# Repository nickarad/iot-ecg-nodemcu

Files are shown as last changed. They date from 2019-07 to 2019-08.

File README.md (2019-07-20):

# Clintelli

<p align="center">
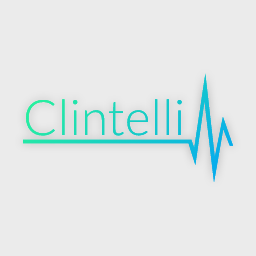
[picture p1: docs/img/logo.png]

</p>

Clintelli stands for Clinical Intelligence and is a platform that leverages Artificial Intelligence and wearable IoT technologies to monitor clinical data and improve patient care.

- [Hackaday 2019 Project](https://hackaday.io/project/165310-clintelli)
- [Documentation](https://nickarad.github.io/clintelli/)

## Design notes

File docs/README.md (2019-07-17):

# Clintelli

Clintelli stands for Clinical Intelligence and is a platform that leverages Artificial Intelligence 
and wearable IoT technologies to monitor clinical data and improve patient care.

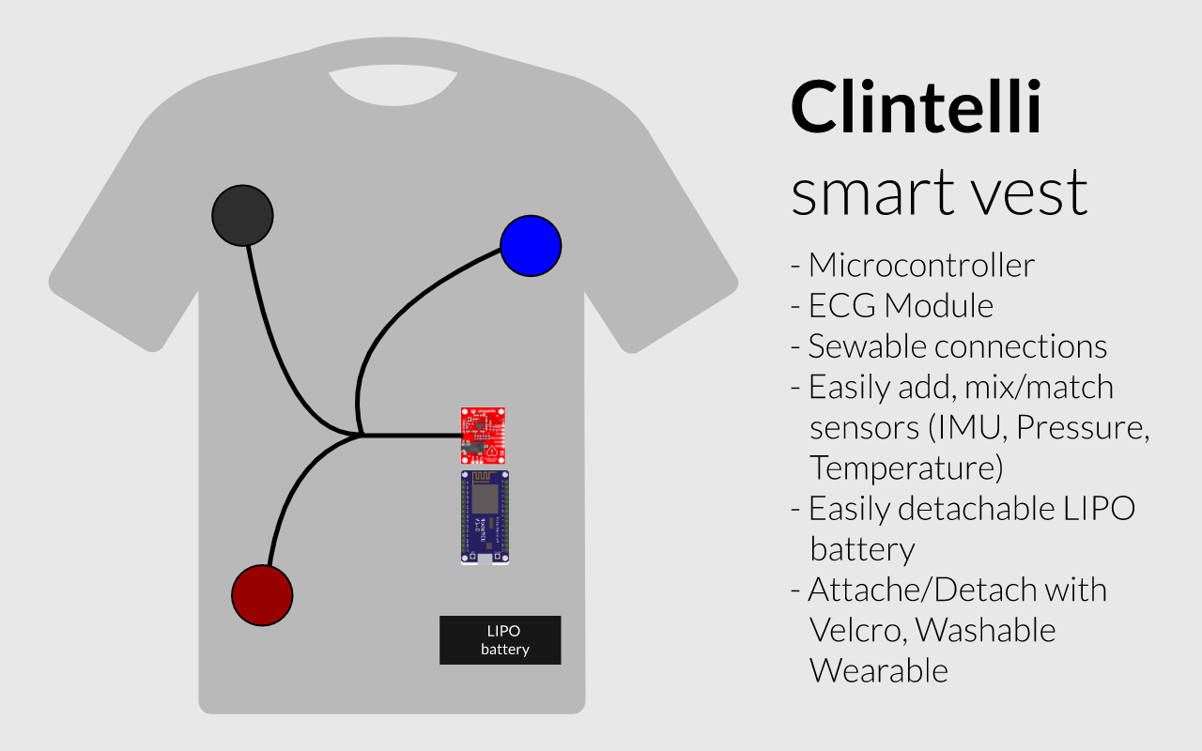
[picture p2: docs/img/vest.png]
clintelli-vest


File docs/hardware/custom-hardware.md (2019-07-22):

# Custom hardware

In order to transform the clintelli IoT wearable prototype into a production ready product, we
decided to design our own customized, open-source, arduino-based microcontroller board, 
the **Clintelli board**.

## Schematics

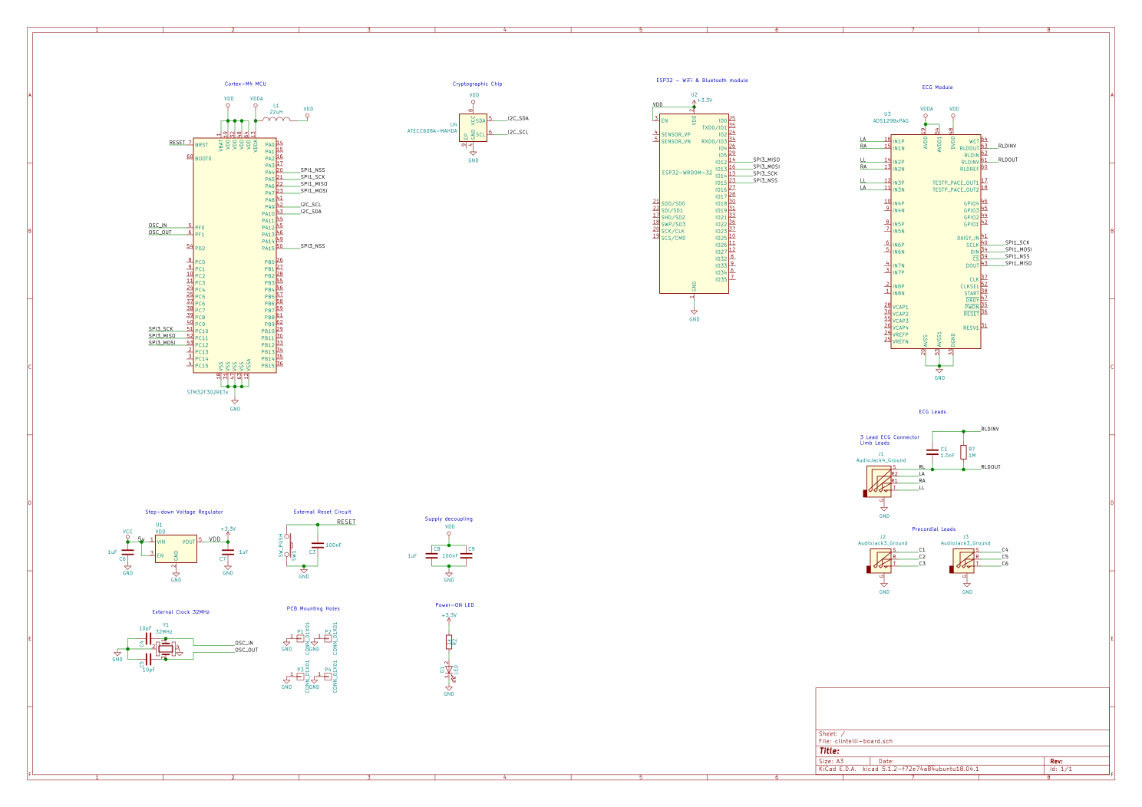
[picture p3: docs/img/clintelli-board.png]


## Components

- Cortex M4 (STM32F302)
- ESP32 (ESP-32-WROOM-32)
- ECG Module (ADS1298)
- Cryptographic chip (ATECC608A)

## ECG Module - MCU SPI

| SPI | ECG GPIO | Cortex M4 Pins | Connection name |
| --- | --- | --- | --- |
| MOSI | 34 | 23 | SPI1_MOSI |
| MISO | 43 | 22 | SPI1_MISO |
| SCK | 40 | 21 | SPI1_SCK |
| SS | 39 | 20 | SPI1_NSS |

## ESP32 Module - MCU SPI

| SPI | ESP32 GPIO | Cortex M4 Pins | Connection name |
| --- | --- | --- | --- |
| MOSI | 13 | 53 | SPI3_MOSI |
| MISO | 12 | 52 | SPI3_MISO |
| SCK | 14 | 51 | SPI3_SCK |
| SS | 15 | 50 | SPI3_NSS |

## PCB Layout

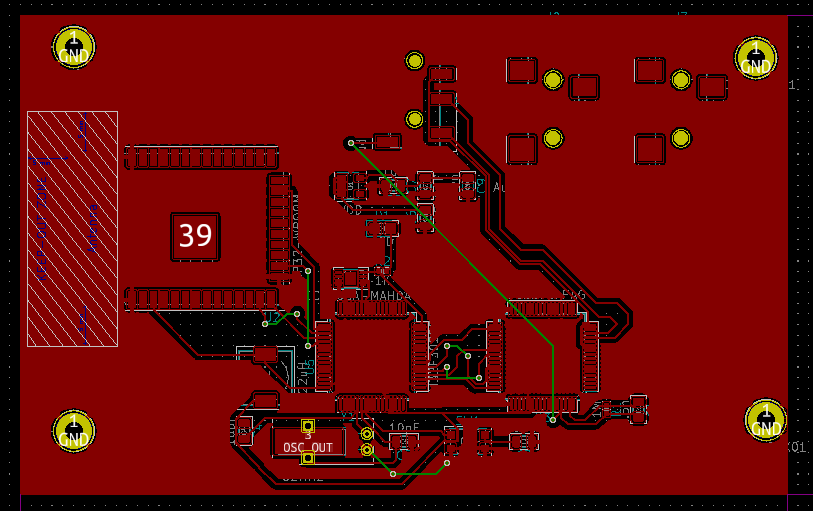
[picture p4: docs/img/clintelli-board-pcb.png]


## PCB Render

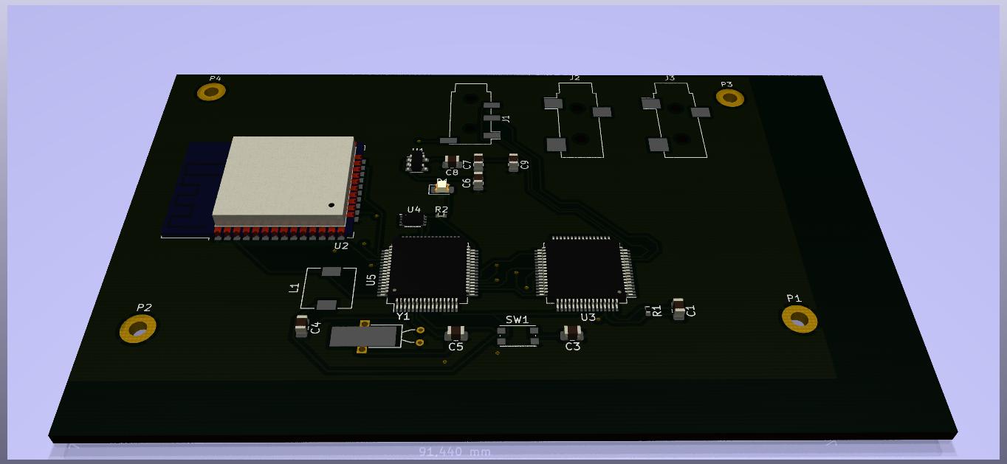
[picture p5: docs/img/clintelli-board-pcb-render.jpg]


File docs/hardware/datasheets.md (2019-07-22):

# Datasheets

- [ARM Cortex-M4 MCU](http://www.st.com/st-web-ui/static/active/en/resource/technical/document/datasheet/DM00133117.pdf)
- [ATECC608A-MAHDA](http://ww1.microchip.com/downloads/en/DeviceDoc/ATECC608A-CryptoAuthentication-Device-Summary-Data-Sheet-DS40001977B.pdf)
- [ESP32-WROOM-32](https://www.espressif.com/sites/default/files/documentation/esp32-wroom-32_datasheet_en.pdf)
- [ADS1298xPAG](http://www.ti.com/lit/ds/symlink/ads1298.pdf)

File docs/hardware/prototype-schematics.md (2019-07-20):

# Schematics

## NodeMCU & ECG module

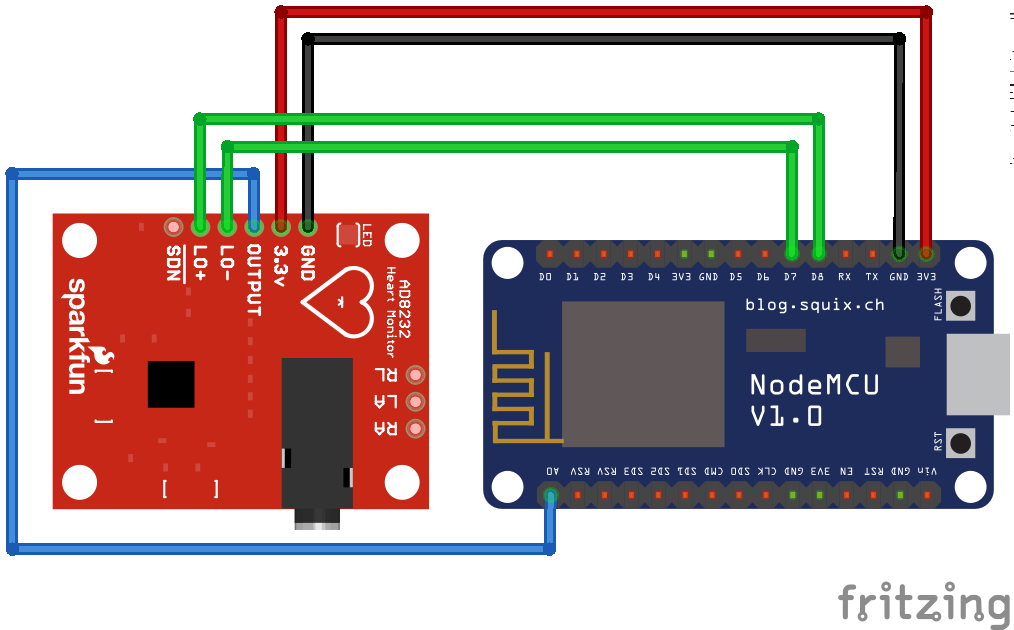
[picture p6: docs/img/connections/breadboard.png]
nodemcu-ecg-breadboard

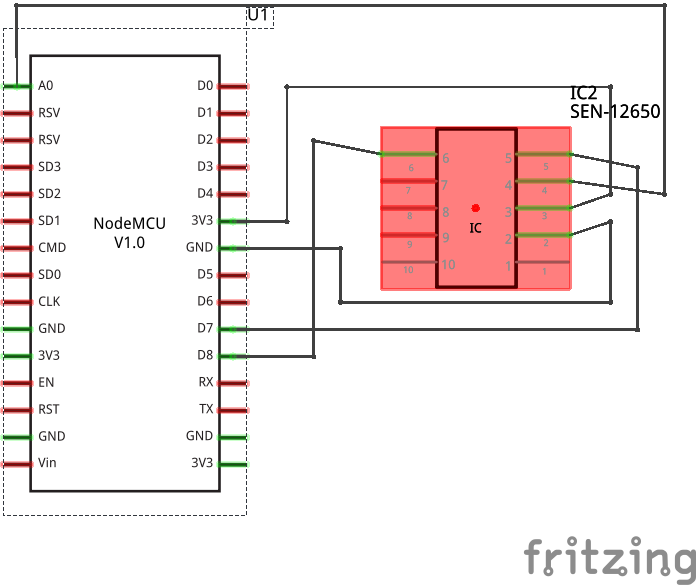
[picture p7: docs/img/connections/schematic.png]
nodemcu-ecg-schematic


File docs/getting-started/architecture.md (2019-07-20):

# Clintelli Platform Architecture

## Platform architecture

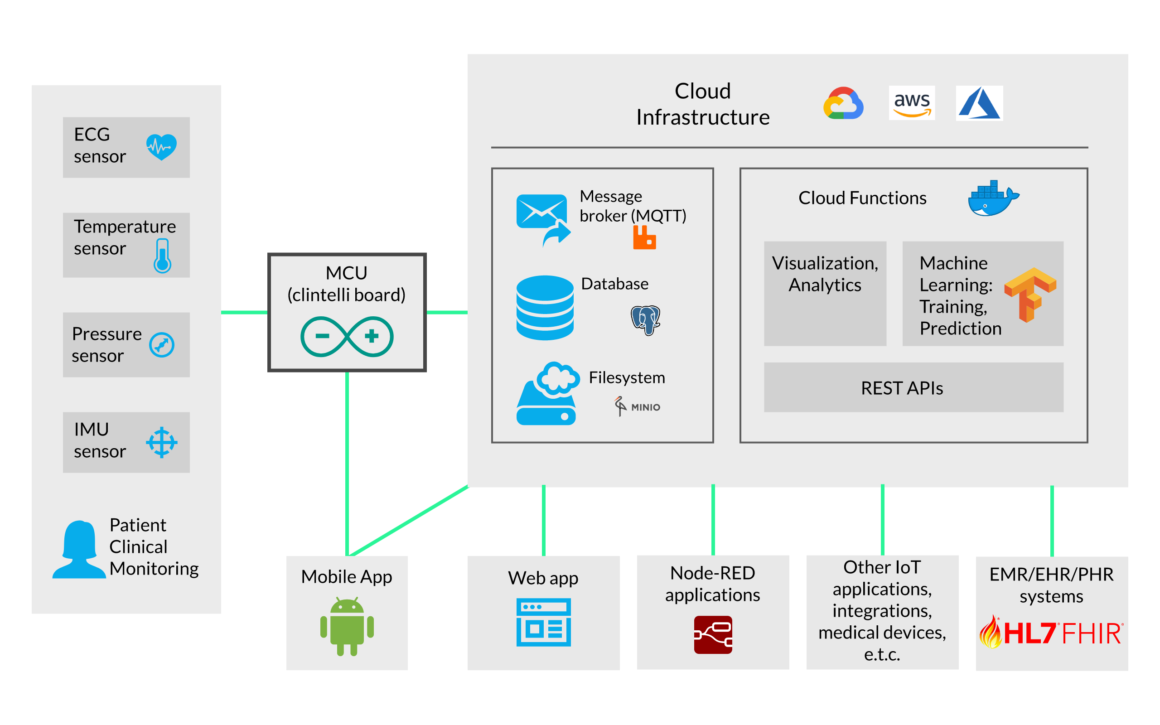
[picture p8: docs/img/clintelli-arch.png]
clintelli-architecture


## Project file structure

- **arduino**: All source code to be compiled and uploaded to an Arduino board
- **cad**: CAD files, Electronics Schematics, PCB layouts, BOMs etc.
- **docker**: Dockerfile and docker-compose configuration file for easily setting up a
    RabbitMQ MQTT server
- **docs**: Clintelli platform documentation
- **sub**: Code for subscribers

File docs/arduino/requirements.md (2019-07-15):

# Requirements

## Hardware

Make sure to prepare the hardware and all the necessary connections as described in
[Schematics](schematics.md)

## Libraries used

- PubSubClient
- ESP8266WiFi

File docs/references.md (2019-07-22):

# References

### ESP8266 based Parts for Fritzing
https://github.com/squix78/esp8266-fritzing-parts.git

### AD8232 Heart Rate Monitor 
https://github.com/sparkfun/AD8232_Heart_Rate_Monitor.git

### RabbitMQ for IoT
https://funprojects.blog/2018/12/07/rabbitmq-for-iot/

### RabbitMQ - MQTT Protocol
https://www.rabbitmq.com/mqtt.html

### MQTT Quality of Service 
https://www.hivemq.com/blog/mqtt-essentials-part-6-mqtt-quality-of-service-levels/

### Arduino CLient for MQTT
https://pubsubclient.knolleary.net/index.html

### DIY Arduino
https://github.com/baldengineer/addohms/tree/master/Episode%2023%20Corrected

### Serial Peripheral Interface (SPI)
https://learn.sparkfun.com/tutorials/serial-peripheral-interface-spi/all

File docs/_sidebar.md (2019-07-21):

- [Home](/)
- Getting Started
    - [Architecture](getting-started/architecture.md)
    - [Quickstart](getting-started/quickstart.md)
- Arduino
    - [Requirements](arduino/requirements.md)
    - [Setup](arduino/setup.md)
- Hardware
    - [Prototype Schematics](hardware/prototype-schematics.md)
    - [Custom Hardware](hardware/custom-hardware.md)
    - [Datasheets](hardware/datasheets.md)
- Deployment
    - [RabbitMQ](deployment/rabbitmq.md)
    - [Google Cloud IoT - Deprecated](deployment/google-iot.md)
- [References](references.md)

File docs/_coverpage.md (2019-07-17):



# Clintelli <small>0.1</small>

> Clinical Intelligence: modular IoT wearable and AI for clinical data monitoring

[GitHub](https://github.com/nickarad/clintelli)
[Get Started](#clintelli)

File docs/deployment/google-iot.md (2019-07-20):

# Google Cloud IoT setup [DEPRECATED]

## Requirements

- An active Google Cloud account
- Google cloud cli

## Instructions

Create topic
```
gcloud pubsub topics create clintelli-test-topic1 --project=PROJECT_ID
```

Create a subscription to the topic above
```
gcloud pubsub subscriptions create clintelli-test-sub1 --topic-project=PROJECT_ID --topic=clintelli-test-topic1 
```

if you want to avoid specifying each time the project with `--project` flag you can run the following
```
gcloud config set project PROJECT_ID
```

Create IoT registry
```
gcloud iot registries create clintelli-test-registry1 --region=europe-west1 --event-notification-config=topic=clintelli-test-topic1
```

Generate certificates
```
openssl req -x509 -newkey rsa:2048 -keyout clintelli-test-rsa_private.pem -nodes -out rsa_cert.pem -subj "/CN=unused"
openssl ecparam -genkey -name prime256v1 -noout -out clintelli-test-ec_private.pem
openssl ec -in clintelli-test-ec_private.pem -pubout -out clintelli-test-ec_public.pem
```

Store above certificates safely and use them to create a device
```
gcloud iot devices create 'clintelli-test' --region=europe-west1 --registry=clintelli-test-registry1 --public-key=path=./clintelli-test-ec_public.pem,type=es256
```

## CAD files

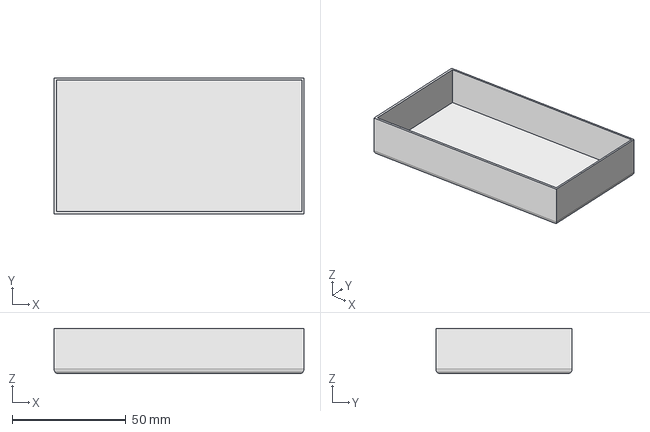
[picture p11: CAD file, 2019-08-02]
cad/board-house/board-house.FCStd
110.0 x 60.0 x 20.0 mm

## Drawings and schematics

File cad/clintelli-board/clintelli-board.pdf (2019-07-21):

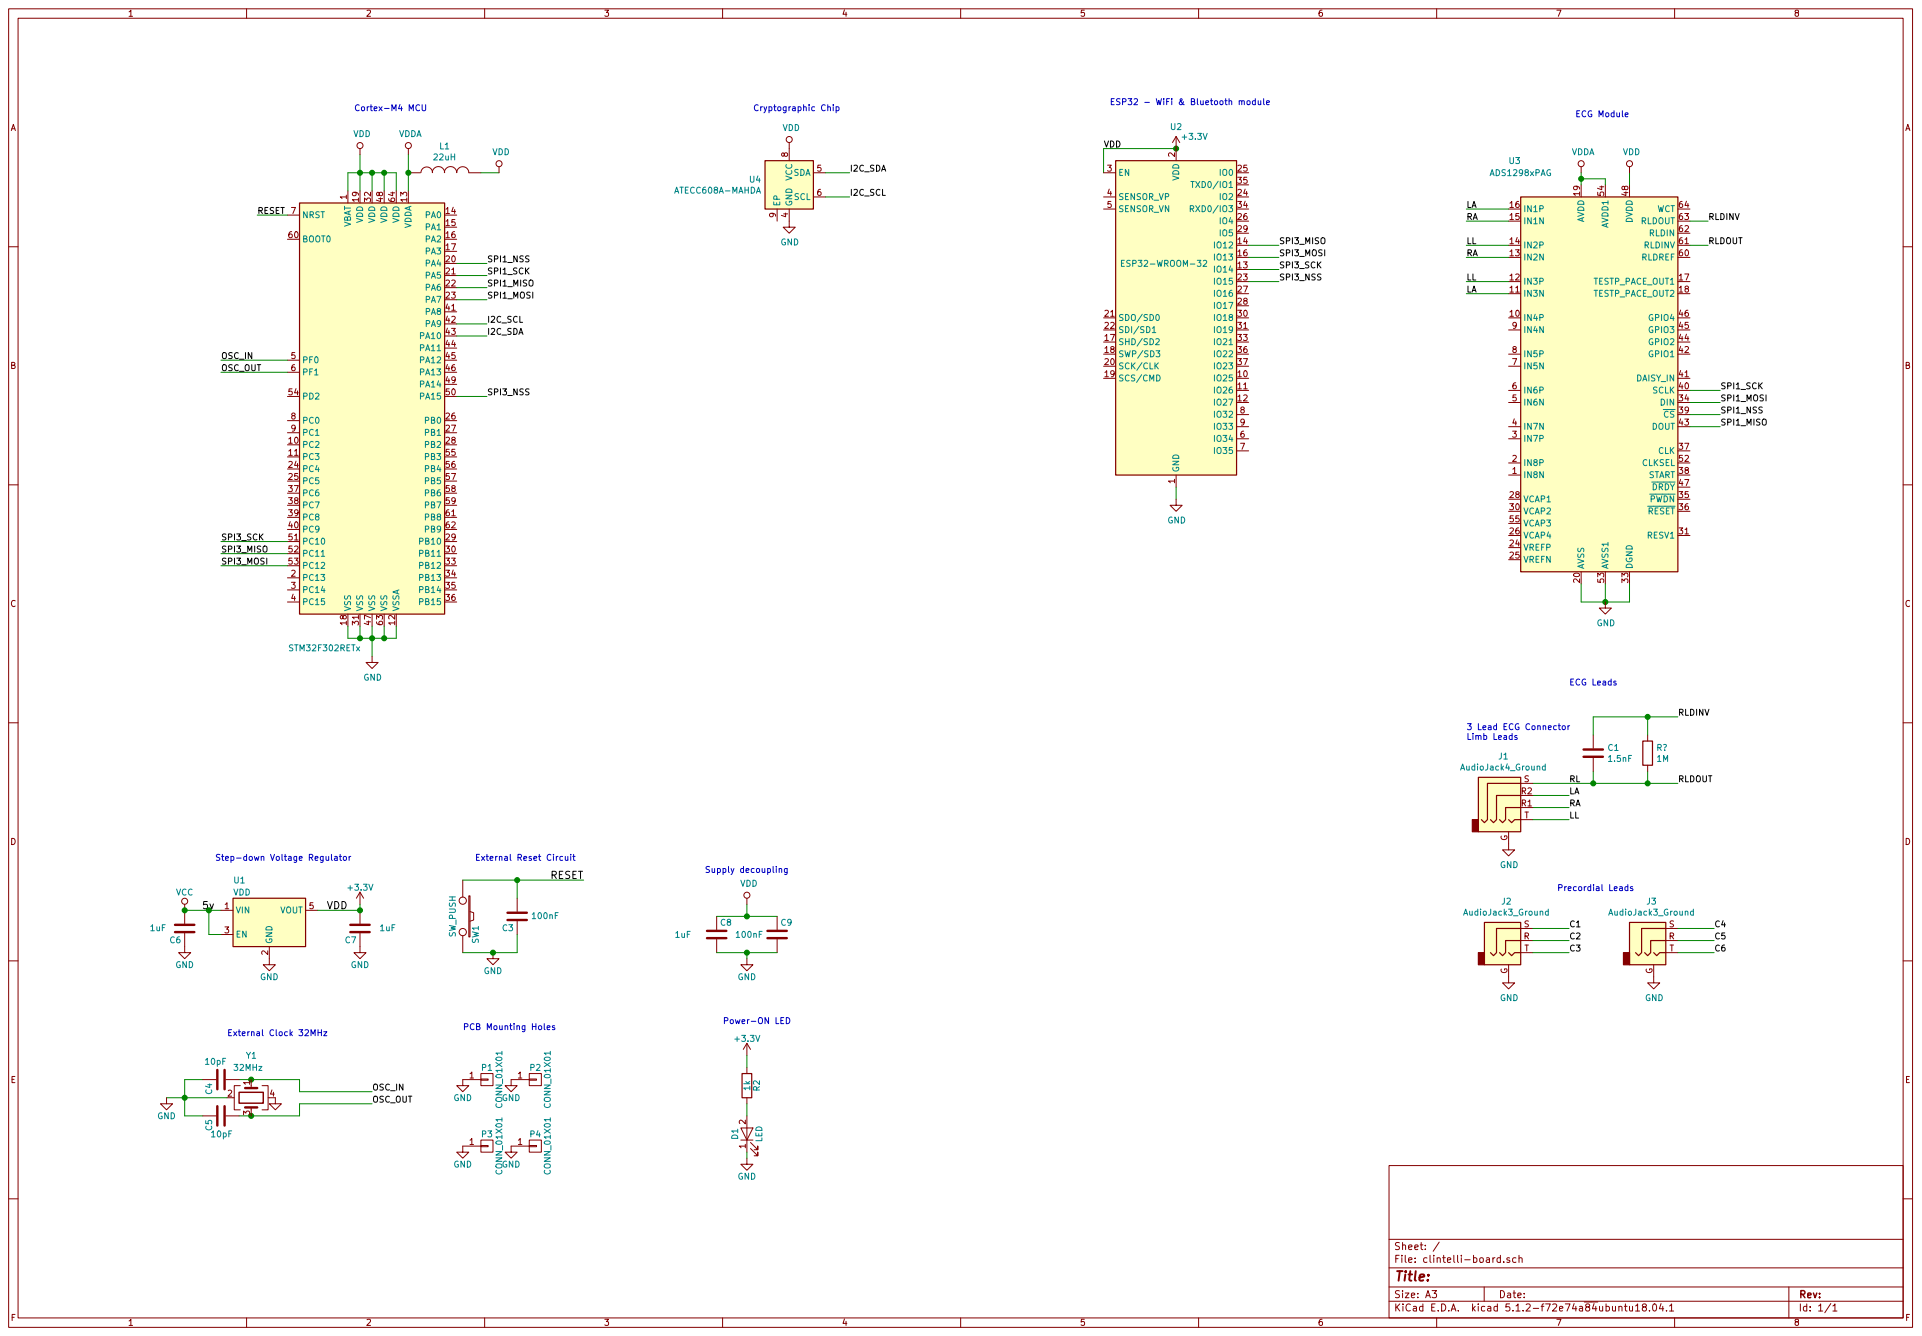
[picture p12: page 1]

VDD
RLDINV RLDOUT RLDINV RLDOUT ECG Leads G

3 Lead ECG Connector Limb Leads

Step-down Voltage Regulator

Id: 1/1 Title: File: clintelli-board.sch Sheet: / GND

PCB Mounting Holes External Clock 32MHz

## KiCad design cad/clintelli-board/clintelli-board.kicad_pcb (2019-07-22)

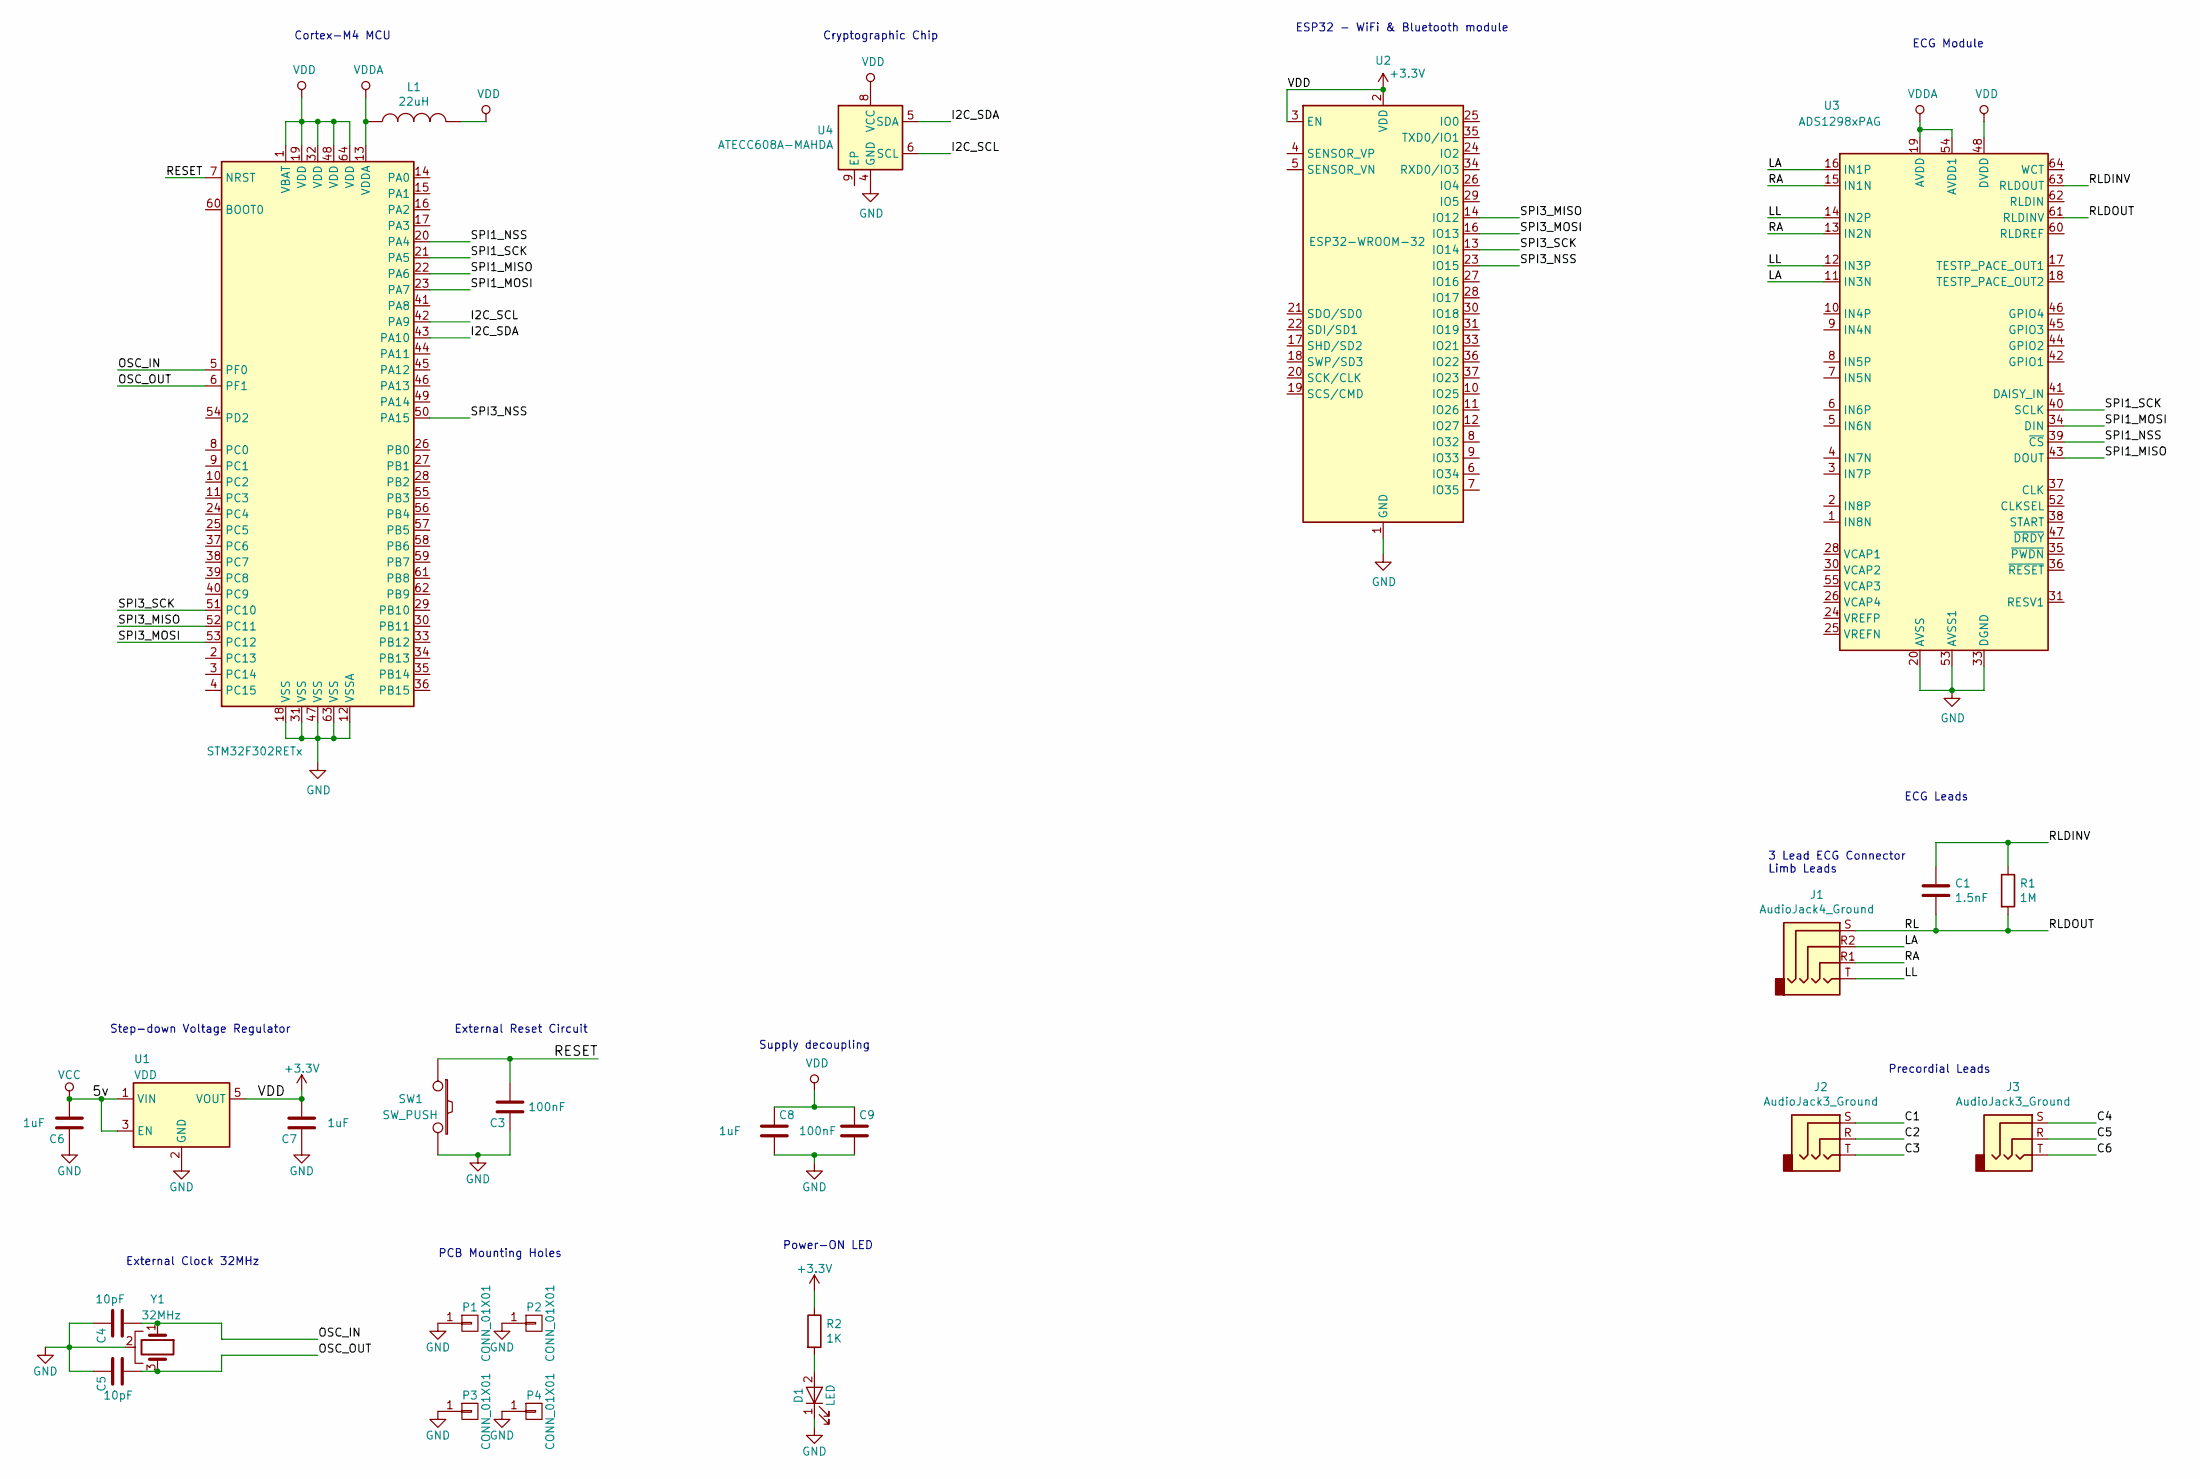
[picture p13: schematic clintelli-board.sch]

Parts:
C1: 1.5nF; C_0805_2012Metric
C3, C9: 100nF; C_0805_2012Metric
C4, C5: 10pF; C_0805_2012Metric
C6, C7, C8: 1uF; C_0805_2012Metric
D1: LED; LED_0805_2012Metric_Castellated
J1: AudioJack4_Ground; Jack_3.5mm_PJ320D_Horizontal
J2, J3: AudioJack3_Ground; Jack_3.5mm_CUI_SJ-3523-SMT_Horizontal
L1: 22uH; L_6.3x6.3_H3
P1, P2, P3, P4: CONN_01X01; MountingHole_2.2mm_M2_Pad
R1: 1M; R_0402_1005Metric
R2: 1K; R_0402_1005Metric
SW1: SW_PUSH; SW_Push_1P1T_NO_CK_KMR2
U1: VDD; SOT-23-5
U2: ESP32-WROOM-32
U3: ADS1298xPAG; TQFP-64_10x10mm_P0.5mm
U4: ATECC608A-MAHDA; DFN-8-1EP_3x2mm_P0.5mm_EP1.3x1.5mm
U5: STM32F302RETx; LQFP-64_10x10mm_P0.5mm
Y1: 32MHz; Crystal_C38-LF_D3.0mm_L8.0mm_Horizontal_1EP_style2

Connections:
+3V3: C7.2, C8.1, C9.1, L1.2, R2.1, U1.5 (VOUT), U2.2 (VDD), U2.3 (EN), U3.48 (DVDD), U3.50 (DVDD), U4.8 (VCC), U5.1 (VBAT), U5.19 (VDD), U5.32 (VDD), U5.48 (VDD), U5.64 (VDD)
/C1: J2.S
/C2: J2.R
/C3: J2.T
/C4: J3.S
/C5: J3.R
/C6: J3.T
/I2C_SCL: U4.6 (SCL), U5.42 (PA9)
/I2C_SDA: U4.5 (SDA), U5.43 (PA10)
/LA: J1.R2, U3.11 (IN3N), U3.16 (IN1P)
/LL: J1.T, U3.12 (IN3P), U3.14 (IN2P)
/OSC_IN: C4.2, U5.5 (PF0), Y1.1
/OSC_OUT: C5.2, U5.6 (PF1), Y1.3
/RA: J1.R1, U3.13 (IN2N), U3.15 (IN1N)
/RESET: C3.2, SW1.1, U5.7 (NRST)
/RL: C1.2, J1.S, R1.2, U3.61 (RLDINV)
/RLDINV: C1.1, R1.1, U3.63 (RLDOUT)
/SPI1_MISO: U3.43 (DOUT), U5.22 (PA6)
/SPI1_MOSI: U3.34 (DIN), U5.23 (PA7)
/SPI1_NSS: U3.39 (~CS), U5.20 (PA4)
/SPI1_SCK: U3.40 (SCLK), U5.21 (PA5)
/SPI3_MISO: U2.14 (IO12), U5.52 (PC11)
/SPI3_MOSI: U2.16 (IO13), U5.53 (PC12)
/SPI3_NSS: U2.23 (IO15), U5.50 (PA15)
/SPI3_SCK: U2.13 (IO14), U5.51 (PC10)
GND: C3.1, C4.1, C5.1, C6.1, C7.1, C8.2, C9.2, D1.1 (K), P1.1, P2.1, P3.1, P4.1, SW1.2, U1.2 (GND), U2.1 (GND), U2.15 (GND), U2.38 (GND), U3.20 (AVSS), U3.23 (AVSS), U3.32 (AVSS), U3.33 (DGND), U3.49 (DGND), U3.51 (DGND), U3.53 (AVSS1), U3.57 (AVSS), U3.58 (AVSS), U4.4 (GND), U5.12 (VSSA), U5.18 (VSS), U5.31 (VSS), U5.47 (VSS), U5.63 (VSS), Y1.2
unnamed: D1.2 (A), R2.2
VCC: C6.2, U1.1 (VIN), U1.3 (EN)
VDDA: L1.1, U3.19 (AVDD), U3.21 (AVDD), U3.22 (AVDD), U3.54 (AVDD1), U3.56 (AVDD), U3.59 (AVDD), U5.13 (VDDA)

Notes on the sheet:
Supply decoupling
External Reset Circuit
Power-ON LED
Step-down Voltage Regulator
PCB Mounting Holes
External Clock 32MHz
Cortex-M4 MCU
ESP32 - WiFi & Bluetooth module
Cryptographic Chip
ECG Module
ECG Leads
3 Lead ECG Connector Limb Leads
Precordial Leads

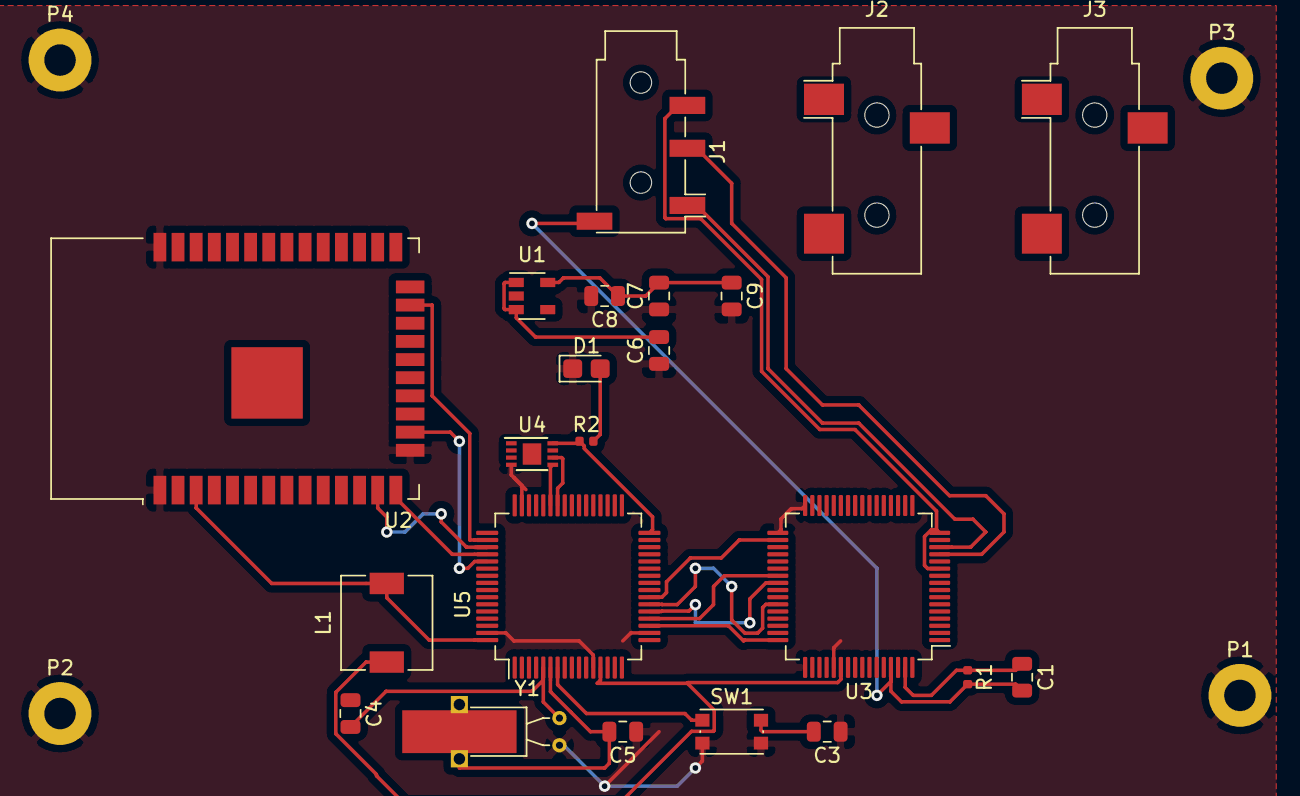
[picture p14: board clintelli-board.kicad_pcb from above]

Board: 2 copper layers, 26 parts (0 on the bottom side), 23 nets.

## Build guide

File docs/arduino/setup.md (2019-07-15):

# Setup

1. Go to `arduino` directory
2. Copy `secret-config.example.h` to `secret-config.h` and update the values based on
    the arduino's WiFi credentials and the RabbitMQ server

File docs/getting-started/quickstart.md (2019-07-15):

# Quickstart

Follow the instructions below to quickly run clintelli platform locally.

1. Start **RabbitMQ** server with Docker. You will need to have Docker and Docker-compose installed
```
cd docker
docker-compose up
```

2. Prepare the arduino code, compile and upload it to your ESP-enabled arduino board. We have tested 
our prototype in a NodeMCU board. See more at [Arduino Setup](arduino/setup.md). Start the arduino microcontroller.

3. Install necessary Python libraries
```
pip install paho-mqtt
```
and then run the simple test subscriber in the `sub` folder
```
python test_sub.py
```

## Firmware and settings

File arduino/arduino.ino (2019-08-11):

/*
 Basic ESP8266 MQTT publish client example
*/
#include <ESP8266WiFi.h>
#include <PubSubClient.h>
#include "secret-config.h"

#define MQTTpubQos		2  
#define Retain			false
#define willMessage 	"exit"
#define cleanSession	false 
#define willTopic		"mq2_mqtt"

WiFiClient espClient;
PubSubClient client(espClient);
String msg;
char payload[50];
unsigned long lastMicros = 0;
const int analogInPin = 17;  

float getECG(void) {
	float analog0;
	// Read from analogic in. 
	analog0 = analogRead(analogInPin);
	// binary to voltage conversion
	// return analog0 = (float)analog0 * 3.3 / 1023.0;
	return analog0;   
}

void setup_wifi() {
	// Connecting to a WiFi network
	WiFi.begin(ssid, password);
	while (WiFi.status() != WL_CONNECTED) {
		delay(500);
		Serial.print(".");
	}
	Serial.println("WiFi connected");
	Serial.println("IP address: ");
	Serial.println(WiFi.localIP());
}

void reconnect() {
	// Loop until we're reconnected
	Serial.println("In reconnect...");
	while (!client.connected()) {
		Serial.print("Attempting MQTT connection...");
		// Attempt to connect
		if (client.connect("Arduino_Gas", mqtt_user, mqtt_pass,willTopic,MQTTpubQos,Retain,willMessage,cleanSession)) {
			Serial.println("connected");
		} 
		else {
			Serial.print("failed, rc=");
			Serial.print(client.state());
			Serial.println(" try again in 5 seconds");
			delay(5000);
		}
	}
}

void setup() {
	Serial.begin(115200);
	setup_wifi();
	client.setServer(mqtt_server, 1883);
}

void loop() {
  
	char msg[8];

	// Desired sample rate T=7812microseconds
	if (micros() - lastMicros > 7812) {
		lastMicros = micros();
		// float temperatureC = getTemperature() ;
		float ecg = getECG();
		sprintf(msg,"%f",ecg);
		// Serial.print("temperature read");
		if (!client.connected()) {
			Serial.print("trying to reconnect...");
			reconnect();
		}

		client.publish("mq2_mqtt", msg);
		//Serial.print("Payload: ");
		Serial.println(msg);
	}
}

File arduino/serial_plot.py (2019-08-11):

import serial
import matplotlib.pyplot as plt
from drawnow import *

values = []
plt.ion()
cnt = 0
#---------------------------------------------------------------------------------------------------------------------------------------------------------------------------------------------------------------------------------------------------
serialArduino = serial.Serial('/dev/ttyUSB0', 115200)

def plotValues():
	plt.title('Serial value from Arduino')
	plt.style.use('ggplot') 
	plt.grid(True)
	plt.ylabel('Values')
	plt.plot(values, 'b')
	plt.legend(loc='upper right')

#pre-load dummy data
for i in range(0,400):
	values.append(0)
	
while True:
	while (serialArduino.inWaiting()==0):
		pass
	valueRead = serialArduino.readline()

	#check if valid value can be casted
	try:
		valueInInt = float(valueRead)
		print(valueInInt)
		if valueInInt <= 1024:
			if valueInInt >= 0:
				values.append(valueInInt)
				values.pop(0)
				drawnow(plotValues)
			else:
				print
				'Invalid! negative number'
		else:
			print("Invalid! too large")
	except ValueError:
		print("Invalid! cannot cast")
	

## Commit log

2019-07-09 Add schematic
2019-07-09 Add fritzing files
    [Heart_Rate_Monitor_demo.fzz, connections.fzz]
2019-07-09 Schematics page
2019-07-14 Sample arduino code for MQTT: code from https://funprojects.blog/2018/12/07/rabbitmq-for-iot/
2019-07-14 arduino secret-config
2019-07-14 get temperature and send it as JSON payload
2019-07-14 Add upload.sh
    Upload arduino code with arduino-cli
    $ bash upload.sh
2019-07-15 Set desired sample rate T=7812microseconds
2019-07-15 ignore arduino compiled files
2019-07-15 Convert Analog read to Celsius Temperature
2019-07-15 fix temperature
2019-07-17 clintelli-board initial schematics
    [clintelli-board.sch]
2019-07-18 Replace temparture with ecg sensor data
    [arduino.ino]
2019-07-20 Separate schematics into prototpye and custom hardware
2019-07-21 Schematic changes: - Replaced ESP8266 with ESP32 - Added AudioJack connector - Removed Header pins
    [clintelli-board.sch]
2019-07-21 Schematic changes: - Annotations - Cortex M4 wiring - Connected ECG with MCU via SPI - Connected 1 ECG Lead
    [clintelli-board.sch]
2019-07-21 Schematic changes: - 12 ECG Leads connectors
    [clintelli-board.sch]
2019-07-21 ESP32 wiring & 1st schematic export
    [clintelli-board.sch]
2019-07-21 CLintelli board - first documentation
2019-07-22 clintelli board datasheets
    [clintelli-board.sch]
2019-07-22 First PCB design attempt
    [clintelli-board.kicad_pcb]
2019-07-22 PCB layout second design attempt
    [clintelli-board.kicad_pcb, clintelli-board.sch]
2019-07-25 mechanical cad files - clintelli board house
    [board-house.FCStd]
2019-07-25 Bootstrap android application
    [app_bar_main.xml]
2019-08-10 commit changes
    [app_bar_main.xml, board-house.FCStd, clintelli-board.kicad_pcb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]
2019-08-11 Fix MQTT Qos & Retain in Publisher
    [arduino.ino]
2019-08-11 Dpwnload CSV file from chronograf
    [2019-08-11-00-03 Chronograf Data.csv]
